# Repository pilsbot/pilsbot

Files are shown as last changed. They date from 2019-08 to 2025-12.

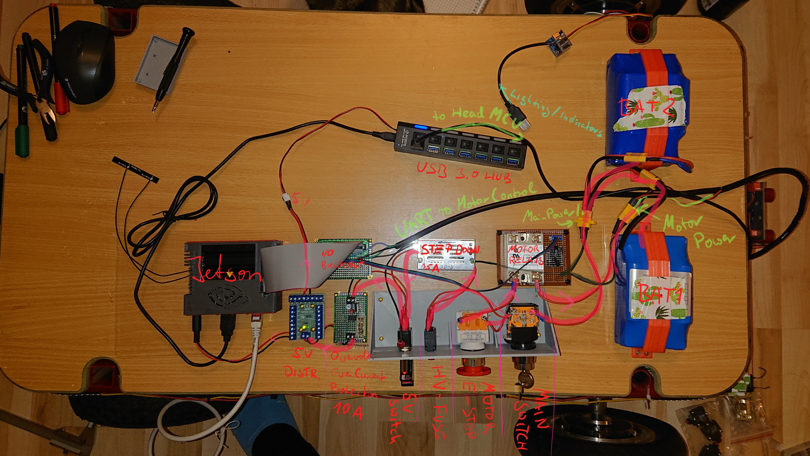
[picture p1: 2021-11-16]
doc/wiring_WIP.jpg

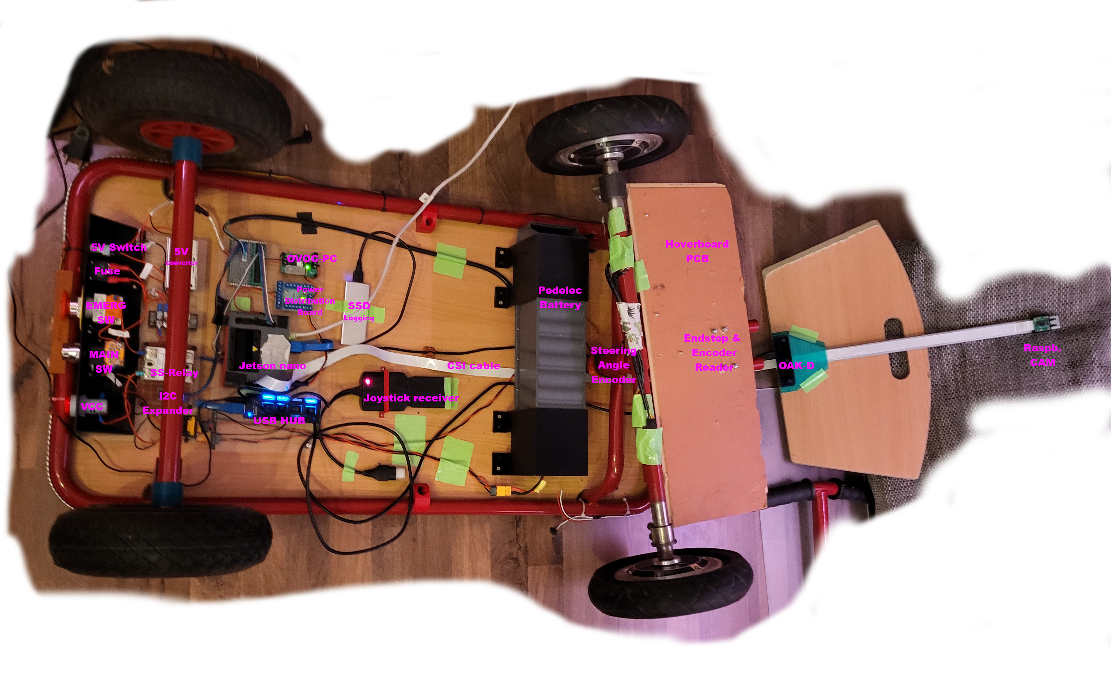
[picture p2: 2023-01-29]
doc/EE-Architecture.jpg

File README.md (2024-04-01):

# pilsbot <a href="https://liberapay.com/pilsbot/donate">Donate using Liberapay</a>
Automate your pils transportation!

lscode: [O+S++I!CE-MV---!PSD-](https://lscodes.pke.fyi/api/decode?q=O+S++IE-MV---!PSD-)

lorry_prototype

This project intends to build an autonomous lorry for transporting pils-beer and other beverages, while following its "flock" - us humans.
It does so by using cheap hoverboard-hub-motors and entry-level robotics equipment (i.e. a jetson nano, OAK-D stereo camera).
The driving is solved simply by measuing the steering angle and odometry along with a mixture of differential drive and ackermann steering, resulting in a new driver - ackerdiff (see https://github.com/pilsbot/pils_control) and the interface to the hoverboard (see https://github.com/pilsbot/pilsbot_hw_ros).

For installation, see [here](https://github.com/pilsbot/pilsbot/wiki/Installation) or [here](https://github.com/pilsbot/pilsbot_vscode_ws).

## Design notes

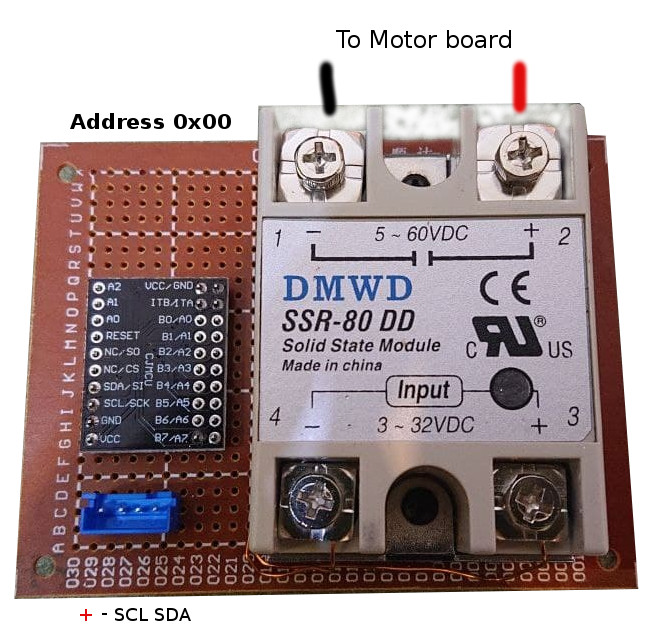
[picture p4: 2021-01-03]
doc/portexpander.jpg

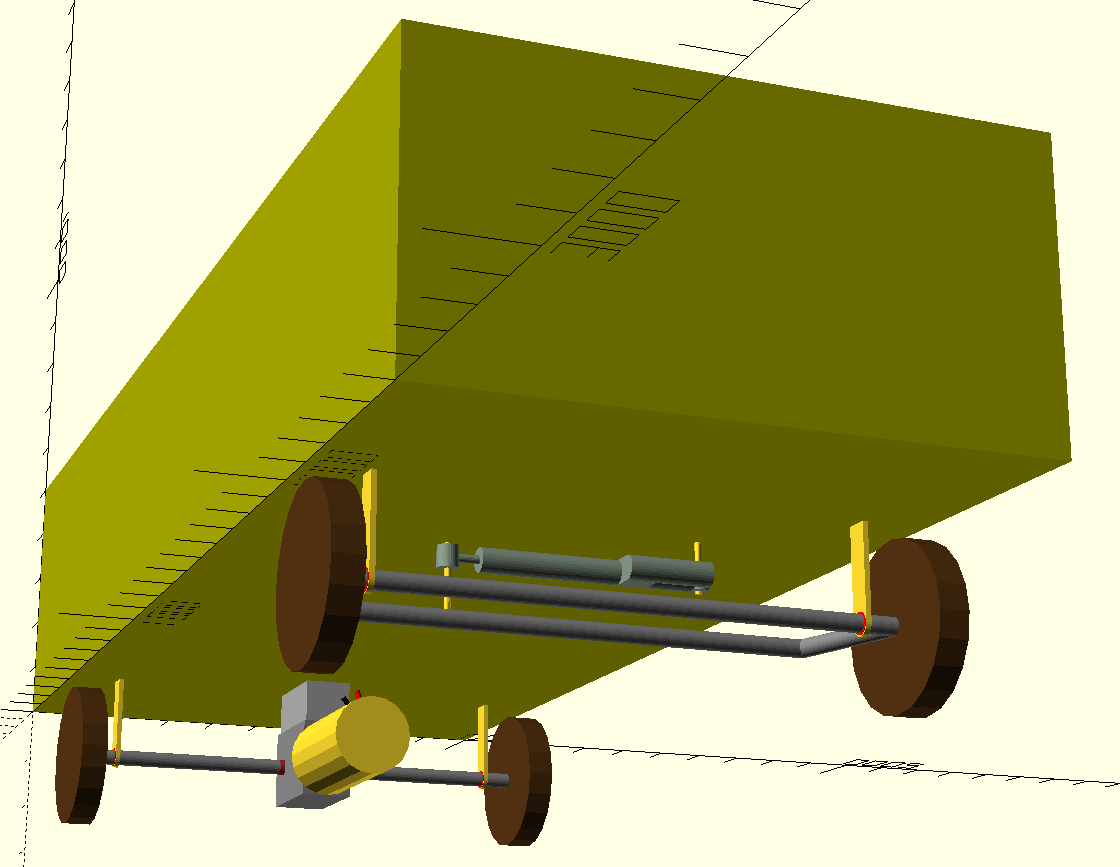
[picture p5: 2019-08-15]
hw-model/export/yee.png

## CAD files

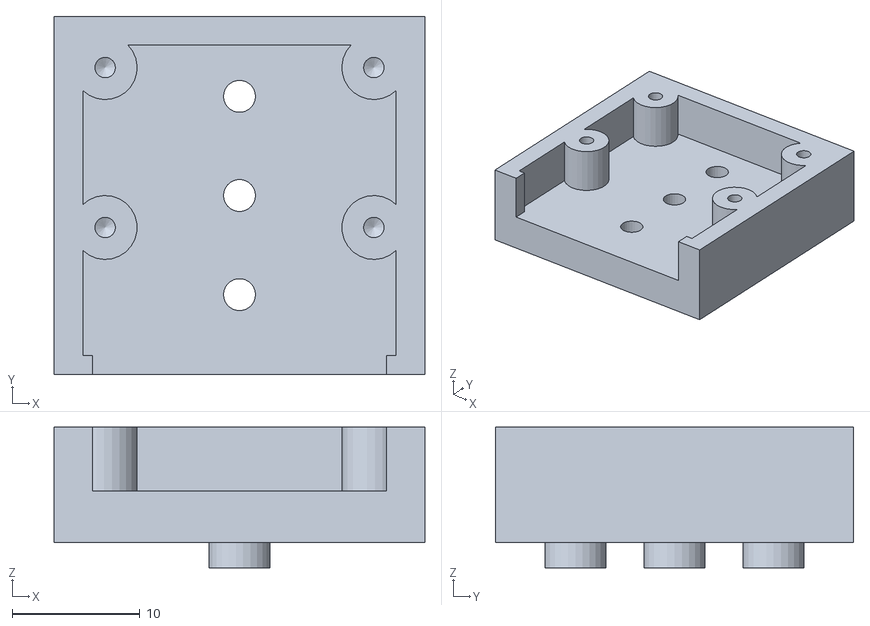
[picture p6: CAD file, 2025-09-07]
hw-model/export/Raspi-Cam-holder-Main_base.stl
29.0 x 28.0 x 11.0

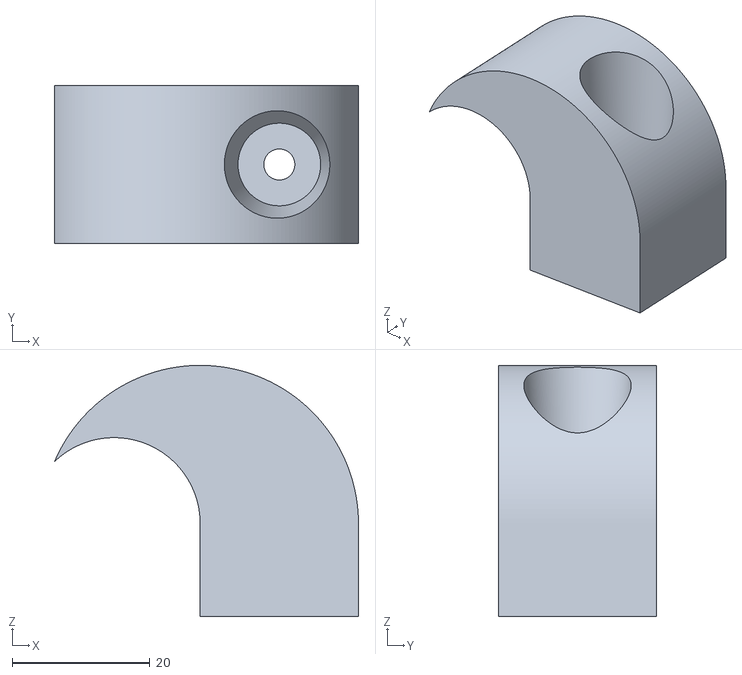
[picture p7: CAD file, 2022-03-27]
hw-model/export/main_plate_clamp.stl
44.2 x 23.0 x 36.5

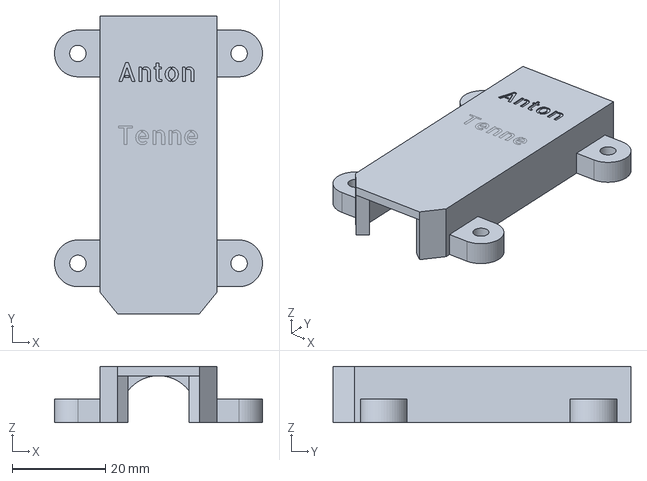
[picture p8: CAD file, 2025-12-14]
hw-model/Bt_Antennenhalter.FCStd
44.5 x 63.7 x 12.0 mm

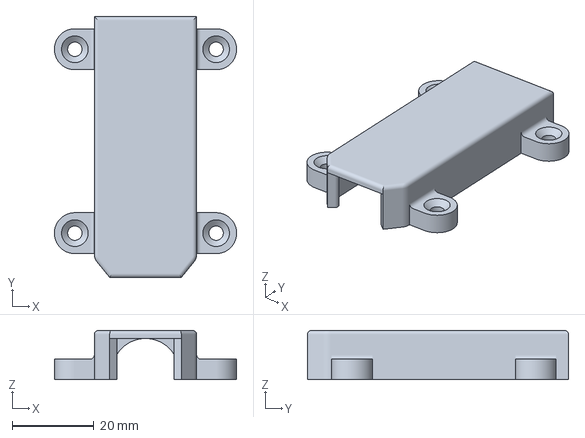
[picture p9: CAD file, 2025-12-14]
hw-model/export/Bt_Antennenhalter-Body.amf
44.5 x 63.7 x 12.0 mm

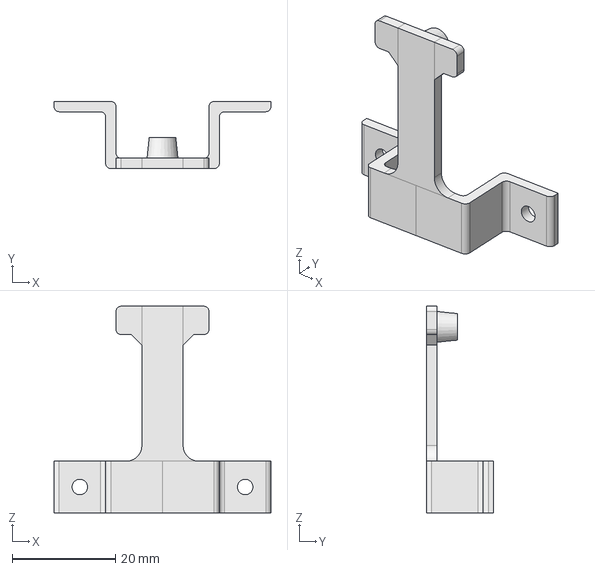
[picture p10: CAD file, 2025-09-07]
hw-model/boom_klemme.FCStd
42.0 x 13.0 x 40.0 mm

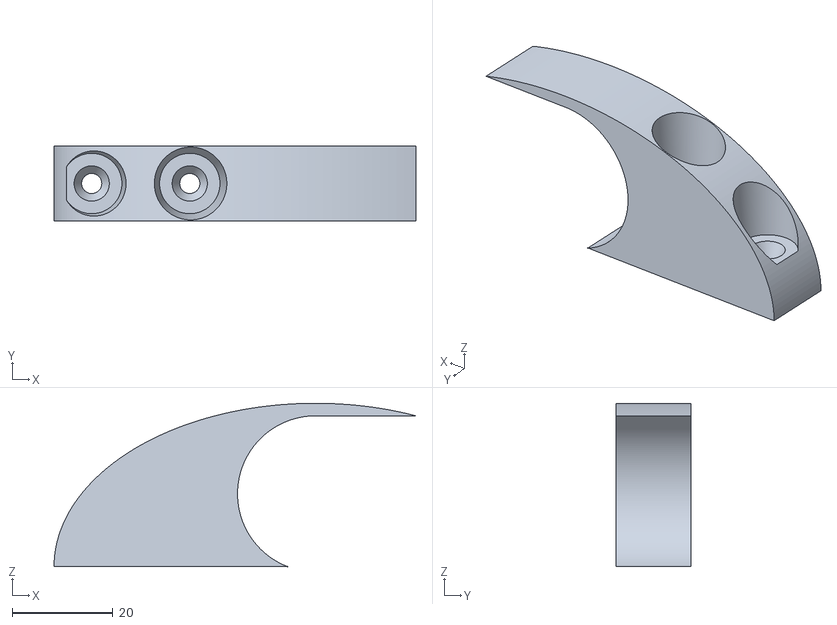
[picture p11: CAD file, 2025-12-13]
hw-model/export/handle_holder.stl
72.0 x 15.0 x 32.5

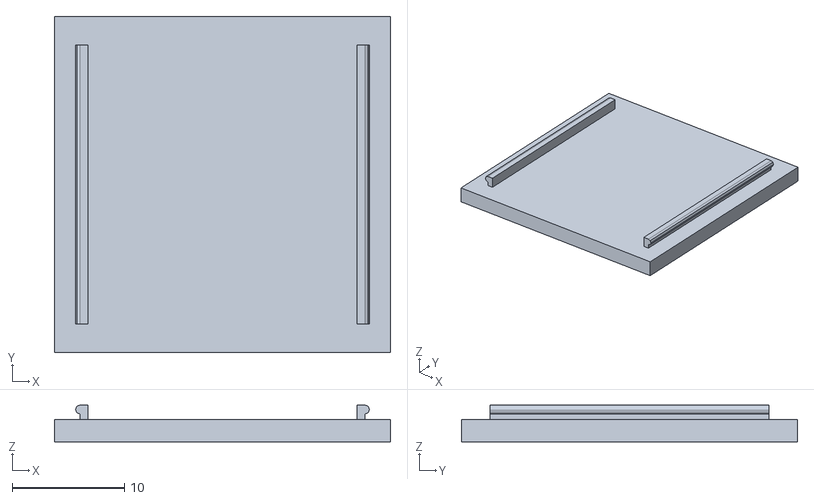
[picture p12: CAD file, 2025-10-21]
hw-model/export/lighting_rp2040_case_deggel.stl
30.0 x 30.0 x 3.30

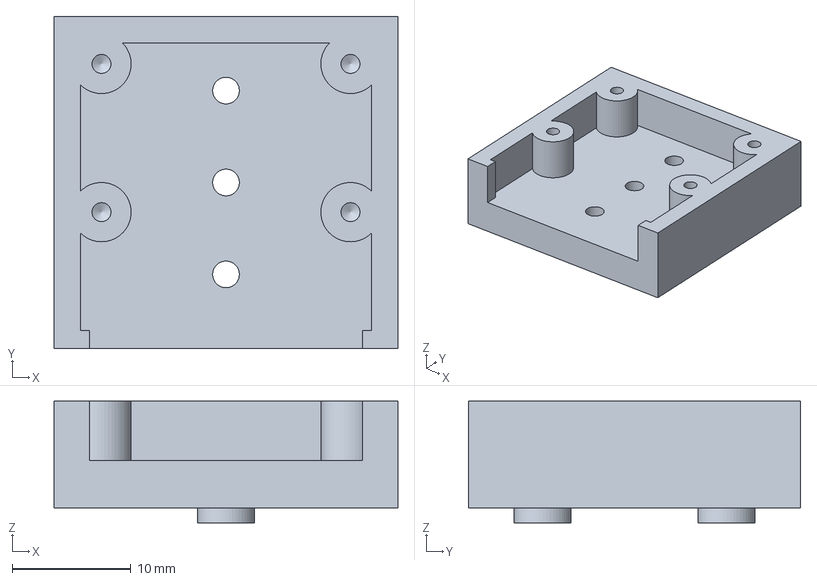
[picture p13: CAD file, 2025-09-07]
hw-model/Raspi-Cam-holder.FCStd
29.0 x 28.0 x 10.2 mm

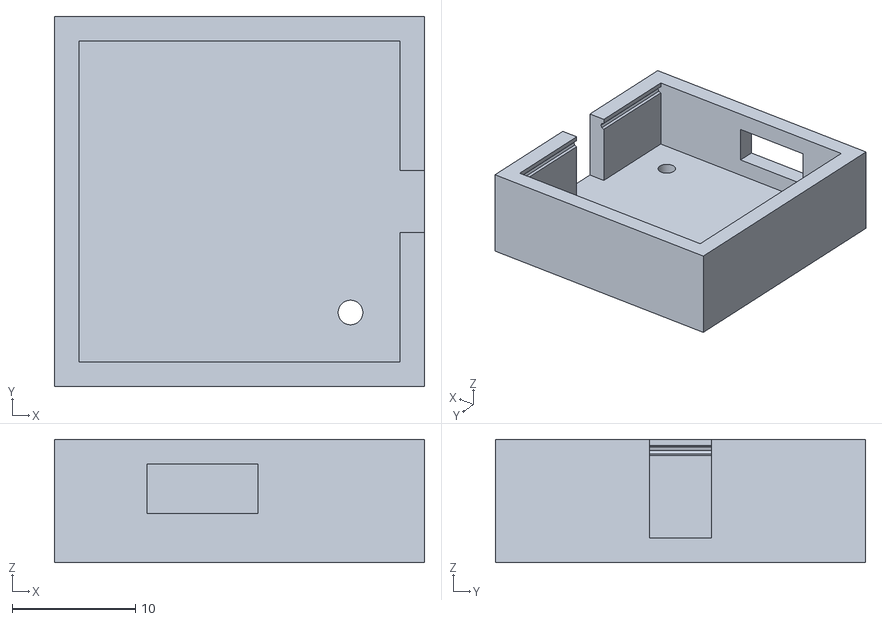
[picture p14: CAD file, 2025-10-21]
hw-model/export/lighting_rp2040_case.stl
30.0 x 30.0 x 10.0

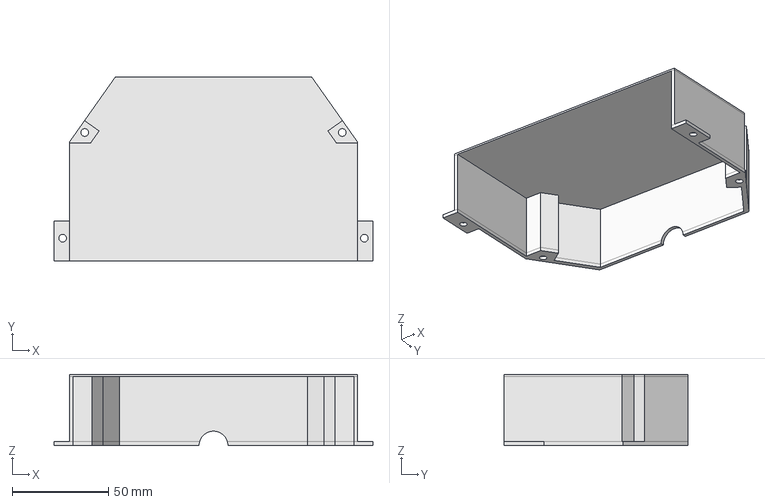
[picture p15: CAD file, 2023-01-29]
hw-model/splash_protection_hb_driver.FCStd
166.0 x 96.0 x 37.0 mm

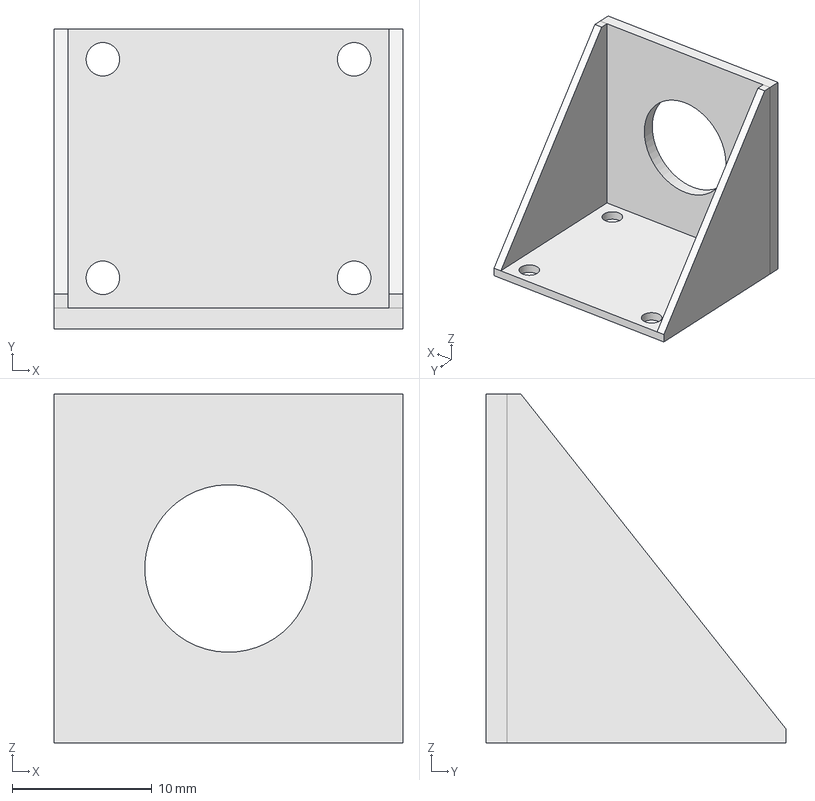
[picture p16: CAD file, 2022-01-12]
hw-model/hoverboard_button.FCStd
25.0 x 21.5 x 25.0 mm

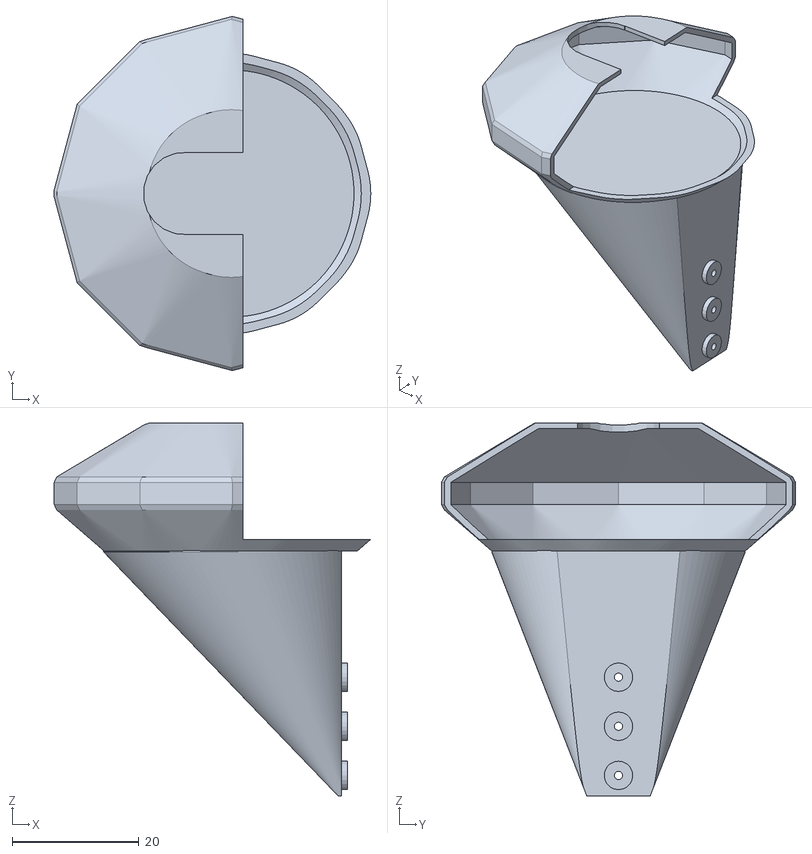
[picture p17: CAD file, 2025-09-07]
hw-model/export/GNSS_Holder.stl
50.0 x 55.9 x 58.9

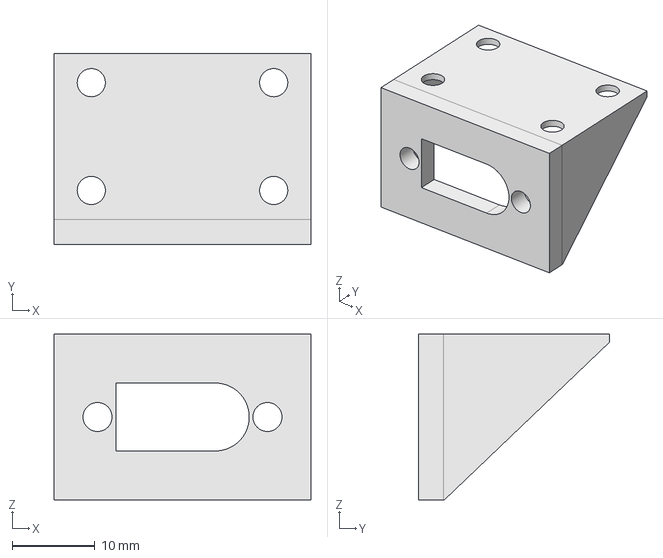
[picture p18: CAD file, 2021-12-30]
hw-model/XT-60_female_blende.FCStd
31.0 x 23.0 x 20.0 mm

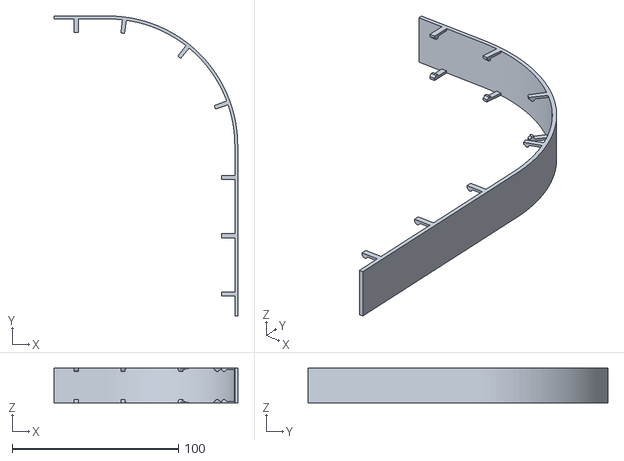
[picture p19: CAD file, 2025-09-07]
hw-model/export/indicator_slots_front.stl
110.3 x 180.3 x 21.0

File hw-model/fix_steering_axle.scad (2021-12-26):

chassis_tube_d = 26;
axle_tube_d = 23;
holder_w = 140;
grip_w = holder_w/4;
difference_offset=[0,7,13];
ws=2;
cable_extra_space=[9,3];
difference_to_upper_tube=135;	//intentionally a bit taller to have center of mass centered

$fn=$preview ? 50 : 200;

module clip(w_total, w_clip, h, tube_d, cube_offset=0, lolcut=false) {
	difference(){
		upper=[0, (chassis_tube_d)/2, h+tube_d/2];
		union() {
			translate([0, cube_offset, 0])
				cube([w_total, chassis_tube_d+ws, h+tube_d/2]);
			//clip
			translate(upper+[(w_total-w_clip)/2,.5,cube_offset/8]) rotate([0, 90, 0])
				cylinder(d=tube_d+2*ws,h=w_clip);
				
		}
		//side cut
		translate([-.5, -.5+cube_offset-ws, h])
			cube([w_total+1, tube_d/2+1+abs(cube_offset)+ws, lolcut ? tube_d+20 : tube_d-ws]);
		//tube
		translate(upper-[.5,0,0]) rotate([0, 90, 0])
			cylinder(d=tube_d,h=w_total+1);
	}
}

difference(){
	union(){
		clip(grip_w, grip_w, difference_offset.z/2, chassis_tube_d);
		translate([0, difference_offset.y, 0]) mirror([0, 0, 1])
			clip(grip_w, grip_w, difference_offset.z/2, axle_tube_d, -difference_offset.y, true);
	}
	//make this lighter
	translate([-.5, -.5, -(difference_offset.z/2+.5)])
		cube([grip_w+1, (chassis_tube_d)/1.5+1, difference_offset.z+ws+1]);
}

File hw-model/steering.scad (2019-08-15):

servo_h = 80;
servo_d = 60;
servo_axle_d = 10;
servo_material_thickness = 10;

lservo_d = 40;
lservo_l = 420;
lservo_body_l = lservo_l - 50;


module hackermannRing(laufbahn = 50)
{
	innen_d	= servo_axle_d;
	staerke	= 10;
	color("#505050")
	translate([0, -(staerke+innen_d/2), -staerke/2])
		difference()
		{
			union()
			{
				cube([laufbahn+staerke, 2*staerke+innen_d, staerke]);
				translate([laufbahn+staerke, staerke+innen_d/2, 0])
					cylinder(d = 2*staerke+innen_d, h = staerke);
			}
			translate([staerke, staerke, -1])
				cube([laufbahn, innen_d, staerke+2]);
		}
}

module servoHackermann(excenter_range)
{
	holding_plate_w = 3 * servo_material_thickness;

	//servo body
	color("#40B0B0")
	cylinder(d = servo_d, h = servo_h);

	translate([0, 0, servo_h])
		union()
		{
			//axle
			cylinder(d = servo_axle_d, h = 2*servo_material_thickness+1);
			//excenter
			translate([0, 0, 10])
				union()
				{
					//holding plate
					color("#405030")
						union()
						{
							translate([0, -holding_plate_w/2, 0])
								cube([excenter_range, holding_plate_w, servo_material_thickness]);
							cylinder(d = holding_plate_w, h = servo_material_thickness);
							translate([excenter_range, 0, 0])
								cylinder(d = holding_plate_w, h = servo_material_thickness);

						}
					translate([excenter_range, 0, servo_material_thickness])
						//Pin
						color("#405060") cylinder(d = 10, h = servo_material_thickness*1.5);
				}
		}

}

module ring(in_d, out_d, h)
{
	difference()
	{
		cylinder(d=out_d, h = h, center = true);
		cylinder(d=in_d, h = h+2, center = true);
	}
}

module linearServoHackerman(excenter_range)
{
	mount_h = lservo_d-5;
	motor_l = 140;
	color("#809080")
	{
	translate ([0, 0, mount_h/2]) union()
	{
		difference()
		{
			rotate([0, 90, 0])
			{
				cylinder(d = lservo_d, h = lservo_body_l);
				cylinder(d = lservo_d/3, h = lservo_l);
				translate([0, lservo_d, 0]) 
					cylinder(d = lservo_d, h = motor_l);
			}
			hull() scale([1,1,2]) ring(in_d = 10, out_d = lservo_d-5, h = mount_h);
			hull() translate([lservo_l, 0, 0]) ring(in_d = 10, out_d = mount_h, h = lservo_d-5);
		}
		ring(in_d = 10, out_d = lservo_d-5, h = mount_h);
		translate([lservo_l, 0, 0])
			ring(in_d = 10, out_d = lservo_d-5, h = mount_h);
		}
		translate([motor_l-50, 0, -(lservo_d - mount_h)/2])
			cube([50, lservo_d, lservo_d]);
	}
}

module lenkungHackermann()
{
	entfernung = 200;
	wheelbase = achse_vorne-achse_hinten;
	achse_lenkung_l = ((wheelbase-entfernung) / wheelbase) * achse_l;
	quer_lenkung_hinterrad = sqrt((achse_l/2)*(achse_l/2) + wheelbase * wheelbase);
	quer_lenkung_l = (entfernung / wheelbase) * quer_lenkung_hinterrad;

	//somehow calculate this
	steering_travel = 140;

	achse();
	//rechter Reifen
	translate([0, -achse_l/2, 0])
		rad();
	//linker Reifen
	rotate([180, 0, 0]) translate([0, -achse_l/2, 0])
		rad();

	//steuerungsstange
	translate([-entfernung, 0, 0])
		union()
		{
			achse(achse_lenkung_l);
			if(steering_type == "hackermann_rotationsservo")
			{
				translate([achse_d/2, 0, 0])
				union()
				{
					hackermannRing(steering_travel/2);
					//20 is 2*staerke ring
					translate([20 + steering_travel/3, 0, servo_h+2.75*servo_material_thickness])
					{
						rotate([0, 180, 0])
							!servoHackermann(steering_travel/3);
						//servoHalterung
						color("#404040")
						cylinder(d1 = servo_d, d2 = servo_d * 1.5, h = entfernung_achse_kiste - (servo_h+2.75*servo_material_thickness));
					}
				}
			}else if(steering_type == "hackermann_linearservo"){

				translate([0, lservo_l/2, entfernung_achse_kiste/2])
				{
				//upper holder
				translate([0, 0, -5])
					cylinder(d = servo_material_thickness, h = entfernung_achse_kiste/2 + 5);
				//servo
				rotate([0, 0, -90])
					linearServoHackerman();
				}
				//lower holder
				translate([0, -lservo_l/2, 0])
					cylinder(d = servo_material_thickness, h = entfernung_achse_kiste/2 + lservo_d);
			}else{
				echo("Invalid steering type");
				assert(false);
			}
		}


	//links
	translate([0, achse_l/2, 0])
		rotate([0, 0, 90 + atan((achse_l/2) / wheelbase)])
			translate([0, quer_lenkung_l/2, 0])
				achse(quer_lenkung_l);
	//rechts
	mirror([0, 1, 0]) translate([0, achse_l/2, 0])
		rotate([0, 0, 90 + atan((achse_l/2) / wheelbase)])
			translate([0, quer_lenkung_l/2, 0])
				achse(quer_lenkung_l);

	//halter links
	translate([0, achse_l/2 - 50, 0])
		achsenhalter();
	//halter rechts
	translate([0, -(achse_l/2 - 50), 0])
		achsenhalter();
}

module sackermannAufhaengung()
{
	achslaenge	= 20;
	gelenk		= 50;
	rad();
	translate([0, achslaenge/2, 0])
		achse(achslaenge);
	//unten
	color("green")
	translate([-gelenk/2, achslaenge, -gelenk/2])
		cube(gelenk);
	color("#30C090")
	translate([0, achslaenge+gelenk/2, gelenk/2])
		cylinder(d1=gelenk, d2=gelenk*1.4, h = entfernung_achse_kiste - gelenk/2);
}

module lenkungSackermann()
{
	translate([0, -achse_l/2, 0])
		sackermannAufhaengung();

	mirror([0, 1, 0]) translate([0, -achse_l/2, 0])
		sackermannAufhaengung();
}

module lenkung()
{
	if(steering_type == "sackermann")
		lenkungSackermann();
	else
		lenkungHackermann();
}

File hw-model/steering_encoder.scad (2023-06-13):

$fa = $preview ? 8 : 3;
$fs = $preview ? 3 : 0.25;

metal_w = 3;
inner_tube_inner_d = 21;// actually 22, but dents in hull;
inner_tube_outer_d = 26;
inner_tube_hole_d = 5;
inner_tube_screw_hole_d = 5;
outer_tube_inner_d = 35;
outer_tube_hole_d = 3;
hole_offs = 6;
outer_hole_offs = 4; //for small anti-turn hole. -2 for "didn't hit the exact point with the dremel"
lower_ring_height = 40;

ws = 2.4;

pot_d = 6.3;
pot_d_low = 16.5;
pot_h_low = 7;
pot_part_h = 15;
pot_gewinde_h = 6;
pot_gewinde_d = 7.5; // actually 7, but to offer more play
pot_schlitz = 1;
pot_schlitz_h = 6;
pot_kranz_d = 10.5;
pot_kranz_h = 2;
pot_pimmel = [3, 1.5, 4];

tube_height = 80;
rohrversatz = 22;
screw_safety_margin_d = 4;
screw_safety_margin_h = 0;
extra_slack_inner_d = 2; 	//To reduce stresses on pot, try keeping the inner part floating
lessen_slew = 1-0.5;
num_bebbels = 10;
bebbels_extra_inset = .25;
screw_head_d = 10;

schnittsicht = false;

outer = true;
inner = false;

//calculated
pot_turn_h = pot_part_h - pot_gewinde_h;
pot_gesamt_h = pot_part_h + pot_kranz_h + pot_h_low;


module tube(inner_d, outer_d, height)
{
	difference()
	{
		cylinder(d = outer_d, h = height);
		translate([0,0,-.5]) cylinder(d = inner_d, h = height+1);
	}
}

module inner_tube()
{
	difference()
	{
		tube(inner_tube_inner_d, inner_tube_outer_d, tube_height);
		//hole
		translate([0, 0, tube_height - hole_offs]) rotate([90, 0, 0])
			cylinder(d = inner_tube_hole_d, h = inner_tube_inner_d + 10, center=true);
	}
	
}


%translate([0,0,-tube_height])
{
	//inner
	inner_tube();

	//outer
	difference()
	{
		tube(outer_tube_inner_d, outer_tube_inner_d+metal_w, tube_height-rohrversatz);
		//hole
		#translate([0, outer_tube_inner_d/2+5, tube_height - rohrversatz - outer_hole_offs]) rotate([90, 0, ])
			cylinder(d = outer_tube_hole_d, h = outer_tube_inner_d + 10);
	}
}



module poti(extra = true)
{
	pimmel_act = pot_pimmel * (extra ? 1.25 : 1);
	
	cylinder(d = pot_d_low, h= pot_h_low);
	
	translate([0,0,pot_h_low])
	{
		//kranz
		cylinder(d = pot_kranz_d, h= pot_kranz_h);
		//platine
		translate([0, -pot_d_low/2, -1]) cube([15,pot_d_low, 1]);
		//pimmel
		translate([-pimmel_act.x/2, -pot_d_low/2]) cube(pimmel_act);
	}
	//gewinde
	translate([0,0,pot_h_low+pot_kranz_h]) cylinder(d = pot_gewinde_d, h= pot_gewinde_h);
	//rotator
	translate([0,0,pot_h_low+pot_kranz_h+pot_gewinde_h])
		color("grey") difference()
		{
			cylinder(d = pot_d, h= pot_turn_h);
			translate([-pot_schlitz/2, -25, pot_turn_h-pot_schlitz_h]) cube([pot_schlitz, 50, pot_schlitz_h]);
		};
}

module poti_rotated()
{
	translate([0,0,pot_gesamt_h-hole_offs+inner_tube_hole_d/2+ws]) rotate([180,0,90]) poti();
}


//inner
if(inner)
{
	i_h = 2*hole_offs;
	color ("orange") difference()
	{
		union()
		{
			kegel_d = inner_tube_inner_d + 2*ws;
			base_kegel_d = inner_tube_inner_d-extra_slack_inner_d;
			//lower cylinder
			translate([0, 0, - i_h + .5*hole_offs]) cylinder(d = base_kegel_d, h = 1.5*hole_offs);
			//kegel
			cylinder(d1 = kegel_d, d2 = kegel_d/2, h = pot_turn_h-hole_offs+inner_tube_hole_d/2);
		}
		//hole
		translate([0, 0, - hole_offs]) rotate([90])
			cylinder(d = inner_tube_screw_hole_d, h = outer_tube_inner_d + 10, center=true);
		
		scale([1.25,1.1,1])	//Increase X slack
			poti_rotated();
		
		//schnittsicht
		if(schnittsicht)
			translate([0,0, -35]) cube([50, 50, 50]);
	}
}

//Outer dome
if(outer)
{
	difference(){
		color("brown") 
		{
			//lower ring
			translate([0,0,-(rohrversatz+lower_ring_height)])
			{
				// hull
				difference()
				{
					cylinder(h=lower_ring_height, d = outer_tube_inner_d);
					translate([0,0,-.5])
						cylinder(h=lower_ring_height+2, d = inner_tube_outer_d+ws);
				}
				//bebbels
				for(i = [0:num_bebbels])
				{
					rotate([0, 0, i*(360/num_bebbels)]) translate([(inner_tube_outer_d+ws)/2, 0, 0])
						cylinder(d=ws+bebbels_extra_inset, h = lower_ring_height+ws, $fn = 80);
				}
			}
			
			//expansion
			expansion_h = rohrversatz-(hole_offs+screw_safety_margin_h+inner_tube_hole_d/2);
			translate([0,0,-(rohrversatz)])
			{
				difference()
				{
					union()
					{
						difference()
						{
							cylinder(d1=outer_tube_inner_d, d2 = outer_tube_inner_d +2*(screw_safety_margin_d+ws),
								h=expansion_h);
							
							cylinder(d=inner_tube_outer_d+ws, h=expansion_h);
						}
						//bebbels
						for(i = [0:num_bebbels])
						{
							rotate([0, 0, i*(360/num_bebbels)]) translate([(inner_tube_outer_d+ws)/2, 0, 0])
								cylinder(d=ws+bebbels_extra_inset, h = 3*outer_tube_hole_d+ws, $fn = 80);
						}
					}
				translate([0,0,expansion_h/2]) 
					cylinder(d1=inner_tube_outer_d, d2 = outer_tube_inner_d +2*screw_safety_margin_d,
						h=expansion_h/2);
				}
			}
			intersection()
			{
				union()
				{
					extra_d_thickness = 2;
					diameter = outer_tube_inner_d +2*(screw_safety_margin_d);
					
					//middle
					middle_h = 2*(rohrversatz-(expansion_h+hole_offs));
					translate([0,0,-rohrversatz+expansion_h]) difference()
					{
						cylinder(d = diameter +2*ws, h=middle_h);
						cylinder(d1 = diameter, d2 = diameter-(extra_d_thickness+0.5), h=middle_h+1);
					}
					//inpansion (lol)
					top_h = pot_gesamt_h-(hole_offs+inner_tube_hole_d/2+ws)+
							(rohrversatz-expansion_h-middle_h);
					translate([0,0,-rohrversatz+expansion_h+middle_h]) difference()
					{
						
						cylinder(d1 = diameter+2*ws, d2 = diameter*lessen_slew,
							h=top_h);
						cylinder(d1 = diameter-extra_d_thickness, d2 = pot_d_low,	//for better 3d-printability
							h=top_h-ws);
					}
				}
				
				translate([-40, -pot_kranz_d/2, -9]) {
					cube([80, pot_kranz_d, 30]);
					translate([0, pot_kranz_d, 0])
						rotate([135, 0, 0])
							cube([80, pot_kranz_d, 30]);
					mirror([0, 1, 0])
						rotate([135, 0, 0])
							cube([80, pot_kranz_d, 30]);
					
				}
			}
		}
		#poti_rotated();
		
		//screw_slit
		hull()
		{
			translate([0, 0, -hole_offs]) rotate([90, 0, 0]) cylinder(d=screw_head_d,
				h = 2*outer_tube_inner_d, center=true);
			//translate([0, 0, -hole_offs-2*rohrversatz]) rotate([90, 0, 0]) cylinder(d=inner_tube_hole_d+2*ws,
			//	h = 2*outer_tube_inner_d, center=true);
		}

		translate([0, 0, - rohrversatz - (outer_hole_offs)]) rotate([90, 0, 0]) hull()
		{
			cylinder(d = outer_tube_hole_d, h = outer_tube_inner_d + 10, center = true);
			// Disabled langloch for better protection against lift-up slip
			//translate([0, -10, 0])
			//	cylinder(d = outer_tube_hole_d, h = outer_tube_inner_d + 10, center = true);
		}
		
		
		//schnittsicht
		if(schnittsicht)
			translate([0,0, -35]) cube([50, 50, 50]);
	}
}

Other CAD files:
hw-model/schalter_blende.FCStd
hw-model/export/indicator_slots_base.stl
hw-model/head_mcu_case.FCStd
hw-model/export/indicator_slots_both.stl
hw-model/Achsadapter.scad
hw-model/GNSS_Holder.scad
hw-model/OAK-D_Mount.scad
hw-model/SSD_holder.scad
hw-model/achse_abstandshalter.scad
hw-model/antigriff.scad
hw-model/axis_fastener.scad
hw-model/battery_cable_strain_protector.scad
hw-model/battery_holder.scad
hw-model/bigbattery_holder.scad
hw-model/button_holder.scad
hw-model/cable_tie_screwable.FCStd
hw-model/export/Achsadapter.stl
hw-model/export/OAK-D_Mount.stl
hw-model/export/Raspi-Cam-holder-Counter_ding.stl
hw-model/export/Raspi-Cam-holder-Deckel.stl
hw-model/export/SSD_holder_logging.stl
hw-model/export/SSD_holder_root.stl
hw-model/export/XT-60_female_blende-Body.stl
hw-model/export/achse_abstandshalter.stl
hw-model/export/antigriff.stl
hw-model/export/axis_fastener.stl
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

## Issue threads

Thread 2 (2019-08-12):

Choose steering-type

Cirromulus, 2019-08-12:
# Request for comments

## Hardware Ackermann steering (Hackermann)
As seen in preview
Pro:
- Only one servo needed
- Mis-configuration of wheels ruled out
- Supports much more weight

Con:
- Fairly complex hardware construction

## Software Ackermann steering (Sackermann)
Two wheels, two independend servo motors
Pro:
- Easier hardware layout
- Interesting steering modes supported

Con:
- Two servos = more power consumption
- More complex software

ChrisStil, 2019-08-13:
I find Sackermann better because it's easier to build. If you put the two wheel in the middle of the construction, it would be even easier to control

PS: are you sure that Sackerman has a bigger power consumption? You still need an other motor ber Hackermann to throttle. With Sackerman, you could use both motor to throttle no?

Cirromulus, 2019-08-13:
> With Sackerman, you could use both motor to throttle no?
This is not quite right as we are using a single rear motor for throttle. The front axle is intended to be passive, with only steering purposes.
But you are right, Sackermann might be adequate for our purposes.

Cirromulus, 2019-08-14:
Maybe, we just mis-use an existing lorry (e.g. [this from ebay](https://www.ebay.de/itm/Kesser-Bollerwagen-550kg-Transportwagen-Gartenwagen-Geratewagen-Handwagen-Power/222868790222)) and put some actuators on it.

ChrisStil, 2019-08-14:
If you want to put some actuators on it, maybe it would be better to buy a wooden lorry (big enough to put your speakers in it too)... Or build it

Cirromulus, 2019-09-13:
https://www.drive-system.com/elektrozylinder-dszy1-encoder.php
Netter 200er :(

Cirromulus, 2019-09-26:
https://www.motioncontrolproducts.co.uk/products/156/165/gd-linear-actuators/
This one is cheaper.

Closed 2020-05-28.

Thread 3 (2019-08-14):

Aquire Motor & other components

Cirromulus, 2019-08-14:

ChrisStil, 2019-08-14:
Will we use a raspberry pi? If yes, I have a camera that can be inserted in the extra slot (but I have no avaiable raspberry Pi a.t.m.)

Cirromulus, 2019-08-14:
This may be too weak in computing power, but maybe our software expert may answer this @DarthBubi

DarthBubi, 2019-08-15:
Even a Raspberry Pi  4 is too weak in my eyes. If we want to do vision-based tasks, we better go for a [Nvidia Jetson Nano](https://www.mouser.de/datasheet/2/813/jetson-nano-devkit-datasheet-1545728.pdf). Costs about 110 € atm and has more compute power.

Cirromulus, 2019-08-15:
I think, this would be appropriate.
btw: This board seems pretty nice for this price.

Cirromulus, 2020-05-30:
- raspberry camera (Johas 70°)
- raspberry (hat Manu)
- logitech shitcam (PP temporär)
- 1-2 Arduino Pro Micro (erst mal von PP)
- 4-6 Ultraschallsensoren for Obstacle Detection (Joha kauft)
- 2 IR TOF for Stufe detection (Später dann)
- ? Simple laserscanner on bottom for more elegant Obstacle D

DarthBubi, 2020-07-20:
I'll compile a list of components for replacing the Raspberry Pi 3 with a Jetson Nano this week.

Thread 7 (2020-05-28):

Better connection for front axle

Cirromulus, 2020-05-28:
Also some Hülsen for back wheels, so that they dont schleif on the side

Cirromulus, 2020-06-01:
Done, see hw-model/achse_abstandshalter

Closed 2020-06-01.

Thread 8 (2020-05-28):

Get some more Batteries

Cirromulus, 2020-05-28:
When we know, how much battery life we get, we may need more cowbell.

Cirromulus, 2020-06-01:
This one guy from copter-club at Sebi may have enough cells (50 for 45€).
I can use the balancing board from my old dead battery

Cirromulus, 2023-01-08:
Bought a billo-pedelec battery. Seems to work, especially after killing one of the hoverboard-batteries.
TODO: Case out of wood (?) to slide the battery in from the underside.

Cirromulus, 2023-09-17:
Used an assortment-box, works very nicely.

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

Closed 2023-09-17.

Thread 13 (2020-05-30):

Encoder for Steering-angle

Cirromulus, 2020-05-30:
- [x] Adapter for potentiometer
- [x] Pro Micro for Ros Serial to publish Pot-Value
- [x] Endstops
- [x] Driver for Pot/Endstop calibration
- [X] Filter an pre-processed steering angle topic provider

DarthBubi, 2020-06-13:
Use a Potentiometer on top of the stering axle.
Will be connected to the endanschlag

DarthBubi, 2020-07-20:
The steering angle encoder got damaged while testing the Pilsbot. @Cirromulus Needs to be repaired.

Cirromulus, 2020-12-17:
This is done.

Cirromulus, 2021-12-21:
Nice, this works conceptually. Need to fix the mounting bracket, though.

Closed 2021-12-21.

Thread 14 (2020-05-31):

Create a Smartphone App for communication

PimpMyPizza, 2020-05-31:
I'll make a smartphone app ( [With flutter](https://flutter.dev/), so for IOS and Android) in order to communicate with the pilsbot over bluetooth.
Features:
- Control the Robot manually
- Insert GPS-Waypoints

If you have more Ideas, put them here please <3

Cirromulus, 2020-06-01:
Would you include it into the main repo as a submodule, please?

Cirromulus, 2020-06-01:
A suggestion would be a status-page, where you can see all relevant info like
- Battery voltage (percentage)
- perhaps CPU-time
- Some kind of QOS (is this possible with detection errors or similar?)
- Perception of outside world (pointcloud, sensor data)

And a debug-page where you can tune all the parameters.

ps.: Thanks :)

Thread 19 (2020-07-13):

GPS include into microcontroller

Cirromulus, 2020-07-13:
@PimpMyPizza, you said something of an existing driver for your GPS module?

- [ ] Add GPS serial to endstop-microcrontroller
- [ ] Publish shit to ROS

PimpMyPizza, 2020-07-13:
Yes: http://wiki.ros.org/ublox

Cirromulus, 2023-06-11:
With the new USB GPS, we don't need this anymore.

Closed 2023-06-11.

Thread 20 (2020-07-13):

Modify Motion controller for filtered steering angle

Cirromulus, 2020-07-13:
As finish of #13.
Motion Controller shall combine absolute but unprescise steering angle potentiometer and precise but relative Odometry from wheels.
Special consideration needs the possibility of one single wheel slipping, where differential steering would fail otherwise.

An open question remains about whether to use "rotation per time" as input unit, or "steering angle + velocity" (personally preferring last)

Cirromulus, 2021-11-29:
This works at least in simulation now with https://github.com/pilsbot/pils_control.
It turns out that it is more useful if the controller itself is just controlling, but not filtering the steering angle sensor.
This should be processed in another package that also handles the sensor calibration (#13)

Closed 2021-11-29.

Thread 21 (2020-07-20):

Add some lights to the chassis

DarthBubi, 2020-07-20:
A test drive at dusk showed that we need some lights on the Pilsbot. Additionally, blinkers seem to be a nice addition for later stages of the development.
On the hardware side, WS2812 LEDs are a reasonable choice.

Cirromulus, 2020-07-20:
I have enough WS2812 for the bot.
Use cases: Indicators, brake-light, front light. Party-Mode.
Rosserial is available for the ubiquitous ESP-01. As lighting is non-critical, i suppose a wireless connection.

Closed 2021-02-14.

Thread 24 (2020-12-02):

Setup a simulation enivronment

DarthBubi, 2020-12-02:
For offline testing purposes it would be nice to have a simulation.

DarthBubi, 2021-02-14:
The robot spawns in simulation see packages `pilsbot_simualtion` and `pilsbot_description`, but for some reason the plugins are not providing data. Needs further investigation.

DarthBubi, 2021-02-15:
Plugins are working now. Seems like installing the  `gazebo_ros` package didn't install the plugins. Inertia and masses are currently not correct, so the bot is driving strangely.

Cirromulus, 2021-11-29:
First Simulation tests with new `acker_diff_drive` seem promising

Closed 2021-11-29.

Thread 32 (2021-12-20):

Investigate dead usb hub

DarthBubi, 2021-12-20:
The powered USB-3 hub does not provide any data. Need to investigate.

Cirromulus, 2021-12-21:
it is already dead, jim

(it's what killed the jetson, too)
neuen bereits bestellt

Closed 2021-12-21.

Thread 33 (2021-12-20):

Upgrade existing switch panel bracket

DarthBubi, 2021-12-20:
The existing switch panel bracket is missing a voltage meter, and the switch for high level should be less flickable.

Cirromulus, 2021-12-21:
also: add some status LEDs driven by jetson nano

Cirromulus, 2021-12-30:
Status LEDs postponed

Closed 2021-12-30.

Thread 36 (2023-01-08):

Front camera needs long cable

Cirromulus, 2023-01-08:
Perhaps Repeater:

- [https://shop.notavis.com/mipi-repeater.html](https://shop.notavis.com/mipi-repeater.html)
- Or just connector: https://www.ebay.de/itm/284237110358

Cirromulus, 2023-01-08:
Bought connector to see if it works for 1.5m

Cirromulus, 2023-01-18:
Connector works nicely

Closed 2023-01-18.

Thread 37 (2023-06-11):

Jetson gets a bit hot, add a fan

Cirromulus, 2023-06-11:
We need more fans

DarthBubi, 2023-06-12:
Order is placed w/ mounting screws.

DarthBubi, 2023-06-14:
Fan arrived, will test mounting on my own Jetson Nano first.

Cirromulus, 2024-01-17:
Problems arose.
Not with the fan, but unmounted jetson anyways. Now PWM-Controlled noctua is on.

Closed 2024-01-17.

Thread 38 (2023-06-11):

THS1 serial weak?

Cirromulus, 2023-06-11:
When loopback testing `ttyTHS1`, the Serial connection does not work with the long cables, only on direct and breakout board.
`ttyS0` is known to work with jumper cables to said breakout board.

Cirromulus, 2023-06-18:
Alternatively put USB serial link on head.

Cirromulus, 2023-09-17:
Issue with `ttyTHS1` is the same as in [this post](forums.developer.nvidia.com/t/jetson-nano-uart-tx-pins-constantly-incorrect-voltage-levels/178250/8).
Voltage levels are sometimes at 1.xx v, or "in the middle" and jumping up and down.
Unkown reasons, NVidia won't fix, so use `ttyS0` again.

https://www.youtube.com/watch?v=paucVGmLJlI

Closed 2023-09-17.

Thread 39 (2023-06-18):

Migrate Jetson OS root to SSD

Cirromulus, 2023-06-18:
SD card is both slow and potentionally unreliable.
Migrate to bigger USB-connected SSD.

Cirromulus, 2023-06-18:
Thanks @ https://github.com/JetsonHacksNano/rootOnUSB
Seems to work now with SD-Card "jump pad".
Currently big & fast sd-card is still used (serving as a fail-back when SSD not available), but might be replaced by a slow & cheap one.

Closed 2023-06-18.

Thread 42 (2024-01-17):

Bluetooth (and Wifi) reception poor

Cirromulus, 2024-01-17:
During the last field-test, we noticed a very degraded 2.4GHz link (both on the proprietary Medion controller as well as the Bluetooth PS4 Controller).

Upon near inspection, the PCB antenna has a 2.4GHz and a 5GHz cable, which _might_ have been plugged in the wrong way.

Our `AX200NGW` has `MAIN 2` and `AUX 1` and [some](https://www.dell.com/community/en/conversations/networking-internet-bluetooth/what-is-the-difference-if-any-between-aux-and-main-antennas-on-the-truemobile-cards-in-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) [posts](https://community.intel.com/t5/Wireless/Connector-1-and-2-on-AC-8265/m-p/514226) hint that `MAIN 2` is WIFI only (so 5 GHz is ok) and, more importantly, `AUX 1` is Wifi + Bluetooth shared, **so 2.4 GHz**.

Cirromulus, 2024-01-17:
The connectors have been swapped, but more tests are needed.
If it is still too poor, we should use an U.FL to SMA adapter and put something like [this](https://cdn11.bigcommerce.com/s-cftati1t7d/images/stencil/original/products/281/1090/DNC-2122-wifi-waterproof-antenna-2db-2.4G-5.8G-band__39793.1698875720.jpg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) on the back.

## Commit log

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2019-08-13 Mocked Sackermann, Addresses #2
    [pilsbot.scad]
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2019-08-15 I think, I overengineer this
    [pilsbot.scad, pilsbot.stl, steering.scad]
2020-05-25 Bought Bollerwagen, so added axle-adapter for Hoverboard-motors
    [Achsadapter.scad, Achsadapter.stl]
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2020-07-12 fIRXST VERSION OF wheel encoder
    [powerbank_holder.scad, powerbank_holder.stl, steering_encoder.scad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]
2020-07-13 Adapted some numbers #12
    [steering_encoder.scad, steering_encoder_außen.stl]
2020-07-15 less holes for less falling down
    [steering_encoder.scad]
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2020-07-20 Hey mortyyyyyy Screw head is exactly as big as the hole was. Very tedious work getting the encoder on or off.
    [steering_encoder.scad, steering_encoder_außen.stl]
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2020-10-25 Added slack in x and y potentiometer to reduce mechanical stresses
    [steering_encoder.scad]
2020-10-26 More stability
    [steering_encoder.scad]
2020-10-26 Two holed slip stop
    [steering_encoder.scad, steering_encoder_außen.stl, steering_encoder_innen.stl]
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2021-06-11 PCB in factory, lets see the first results
    [overvolt-B_Cu.gbr, overvolt-B_Mask.gbr, overvolt-B_Paste.gbr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]
2021-06-11 Moved overvolt to own repo
    [overvolt-B_Cu.gbr, overvolt-B_Mask.gbr, overvolt-B_Paste.gbr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]
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2021-11-16 Added one part of a new stand
    [upright_stand.scad, upright_stand.stl]
2021-11-16 stand to be printed
    [upright_stand.scad, upright_stand.stl]
2021-11-16 added fixing
    [fix_steering_axle.scad, fix_steering_axle.stl]
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2021-12-26 Better (but still suboptimal) ficature for steering axle
    [fix_steering_axle.scad, fix_steering_axle.stl]
2021-12-26 Added Voltage display. Man, freeCAD is not amused about changes in base geometry
    [schalter_blende.FCStd, schalterblende.stl]
2021-12-27 This FreeCAD really does not like changes, bruh
    [schalter_blende.FCStd, schalterblende.stl, schalterblendeL.stl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]
2021-12-28 Quick & dirty XT-60 female hodler
    [XT-60_female_blende-Body.stl, XT-60_female_blende.FCStd]
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2021-12-30 correctly sized holes
    [XT-60_female_blende-Body.stl, XT-60_female_blende.FCStd]
2021-12-30 More exact hole for supressing z-axis slip
    [steering_encoder.scad, steering_encoder_außen.stl]
2021-12-30 Added feet for mountplate to be fixed onto bollerwagen plate
    [mountplate_feet.scad, mountplate_feet.stl]
2021-12-30 Didn't hit the hole exactly
    [steering_encoder.scad, steering_encoder_außen.stl]
2022-01-12 Added holder for the hoverboard button
    [hoverboard_button.FCStd, hoverboard_button.stl]
2022-03-26 Added untested clamp model
    [main_plate_clamp.scad, main_plate_clamp.stl]
2022-03-26 Increased clearance
    [mountplate_feet.scad, mountplate_feet.stl]
2022-03-26 Eh, something about clearance and less slip for anti-turn hole
    [steering_encoder.scad, steering_encoder_außen.stl, steering_encoder_innen.stl]
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2022-03-27 Better clearance
    [main_plate_clamp.scad, main_plate_clamp.stl]
2023-01-08 Added Raspi cam holder on aluprofil
    [Raspi-Cam-holder-Counter_ding.stl, Raspi-Cam-holder-Main_base.stl, Raspi-Cam-holder.FCStd]
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2023-01-17 Initial version of handle holder
    [handle_holder.scad, handle_holder.stl]
2023-01-19 First version of OAK-D mount that doubles as (rain) protective cap for CSI-Cable
    [OAK-D_Mount.scad, OAK-D_Mount.stl]
2023-01-21 Initial version of cable strain protector
    [battery_cable_strain_protector.scad, battery_cable_strain_protector.stl]
2023-01-21 First steps for battery slide-in holder for big Battery
    [bigbattery_holder.scad]
2023-01-21 Initial version of back side battery Holder cup
    [bigbattery_holder.scad, bigbattery_holder_back.stl]
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2023-01-21 Comply with screwas poking out
    [bigbattery_holder.scad, bigbattery_holder_back.stl]
2023-01-21 Added Slit for piping cables
    [bigbattery_holder.scad, bigbattery_holder_back.stl]
2023-01-21 Increased clearance to battery
    [bigbattery_holder.scad, bigbattery_holder_back.stl]
2023-01-21 All the right holes in all the right places
    [bigbattery_holder.scad, bigbattery_holder_back.stl]
2023-01-21 Added inital version of holder for splashwaterbox
    [water_splash_plate_holder.scad, water_splash_plate_holder.stl]
2023-01-22 Da war ja was
    [bigbattery_holder.scad, bigbattery_holder_back.stl]
2023-01-22 Added front holder. Even more clearance needed, TODO: Check if still fits
    [bigbattery_holder.scad, bigbattery_holder_front.stl]
2023-01-28 Improved Clearance
    [bigbattery_holder.scad, bigbattery_holder_back.stl, bigbattery_holder_front.stl]
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2023-01-29 Initial version of Deckel
    [Raspi-Cam-holder-Deckel.stl, Raspi-Cam-holder.FCStd]
2023-01-29 Added Taper to allow for more water to just wash off. TODO: Is this contraproducti ve? Also, should a top shield for the camera objective be added?
    [Raspi-Cam-holder-Deckel.stl, Raspi-Cam-holder.FCStd]
2023-01-29 Initial version of HB-driver protection
    [splash_protection_hb_driver-Abdeckung.stl, splash_protection_hb_driver.FCStd]
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2023-02-14 Initial version of Navsat-Receiver holder sock
    [GNSS_Holder.scad, GNSS_Holder.stl]
2023-02-14 Initial Version of ssd holder
    [SSD_holder.scad, SSD_holder.stl]
2023-06-11 Steering encoder capsule now stronger and less play. Todo: test
    [steering_encoder.scad, steering_encoder_außen.stl]
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2024-02-20 Increased wall strength a bit, considering that it was destroyed by a boßelball
    [indicator_slots.scad, indicator_slots.stl]
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2024-03-08 Zip-slots now more on the important places (außen)
    [indicator_slots.scad, indicator_slots.stl]
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2024-06-01 Axis fastener to fasten now without destroying it
    [axis_fastener.scad, axis_fastener.stl]
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2025-09-07 Indicator Slots now even more rugged, also GNSS and cam Holder fitting to the movable boom (Schubladenschiene)
    [GNSS_Holder.scad, GNSS_Holder.stl, Raspi-Cam-holder-Main_base.stl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]
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2025-10-21 Added tabs for rp2040 holder so that the deggel does not fall off that easily
    [lighting_rp2040_case.scad, lighting_rp2040_case.stl, lighting_rp2040_case_deggel.stl]
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2025-10-21 Noticed that more wiggle room would be nice
    [lighting_rp2040_case.scad, lighting_rp2040_case_deggel.stl]
2025-10-21 Fixup: Unintentionally deleted a line
    [lighting_rp2040_case.scad]
2025-12-13 Made manual override holder a little more sturdy
    [handle_holder.scad, handle_holder.stl]
2025-12-14 Maybe fitting Antenna holder for better Bluetooth coverage
    [Bt_Antennenhalter-Body.amf, Bt_Antennenhalter.FCStd]
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
